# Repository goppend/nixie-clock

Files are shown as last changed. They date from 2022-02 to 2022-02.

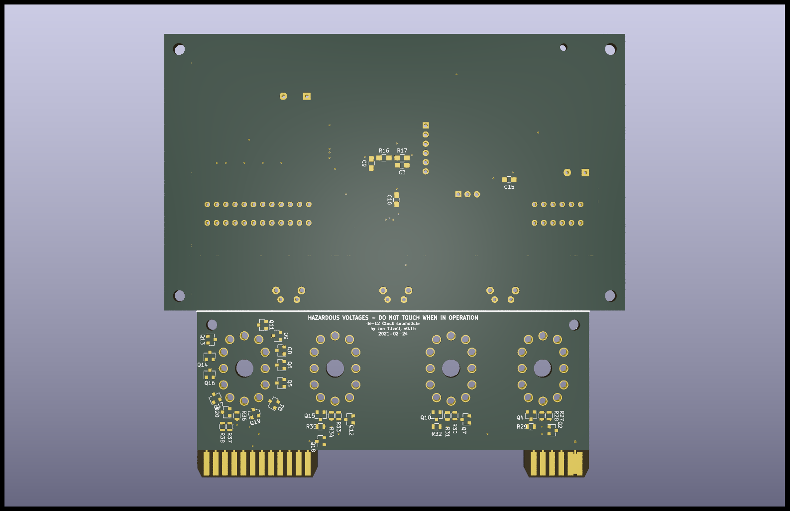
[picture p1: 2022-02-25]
pics/main reverse.png

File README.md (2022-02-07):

# Nixie Tube Clock (wip)

A nixie clock using IN-12 tubes, featuring a modular and efficient design.

## Todo
- [x] Port what I have to KiCad.
- [x] Fix existing problems.
- [x] Consider design changes, add last minute features, ERC.
- [x] Ensure layout is sound. DRC.
- [x] Have boards fabbed.
- [ ] (Awaiting boards/parts) Write firmware.
- [ ] Done!

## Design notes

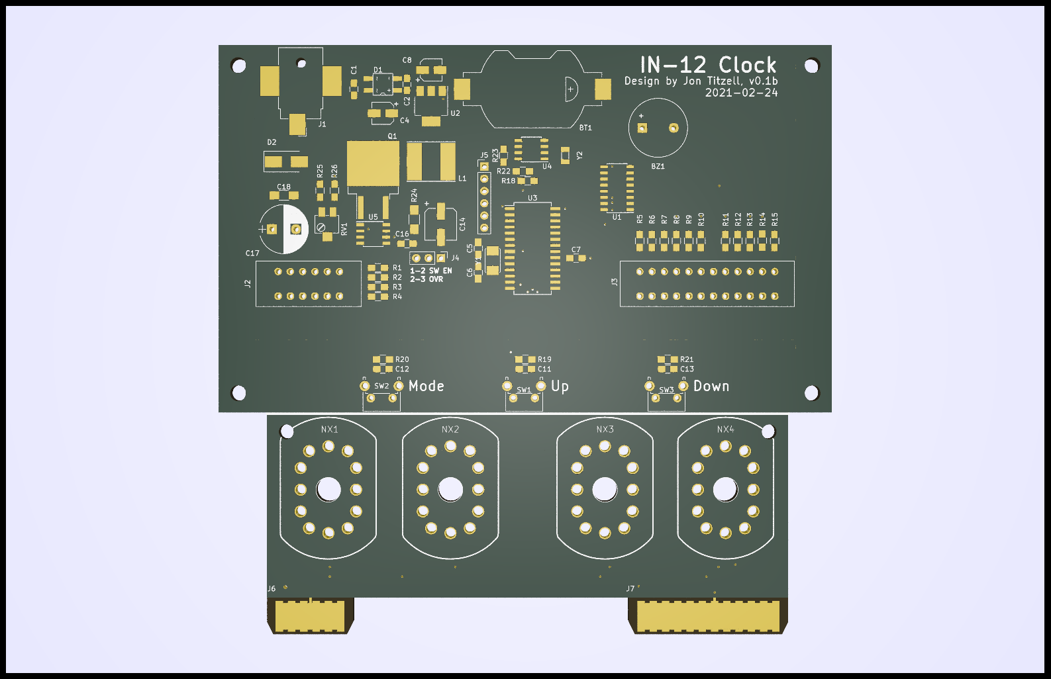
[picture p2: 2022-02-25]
pics/main.png

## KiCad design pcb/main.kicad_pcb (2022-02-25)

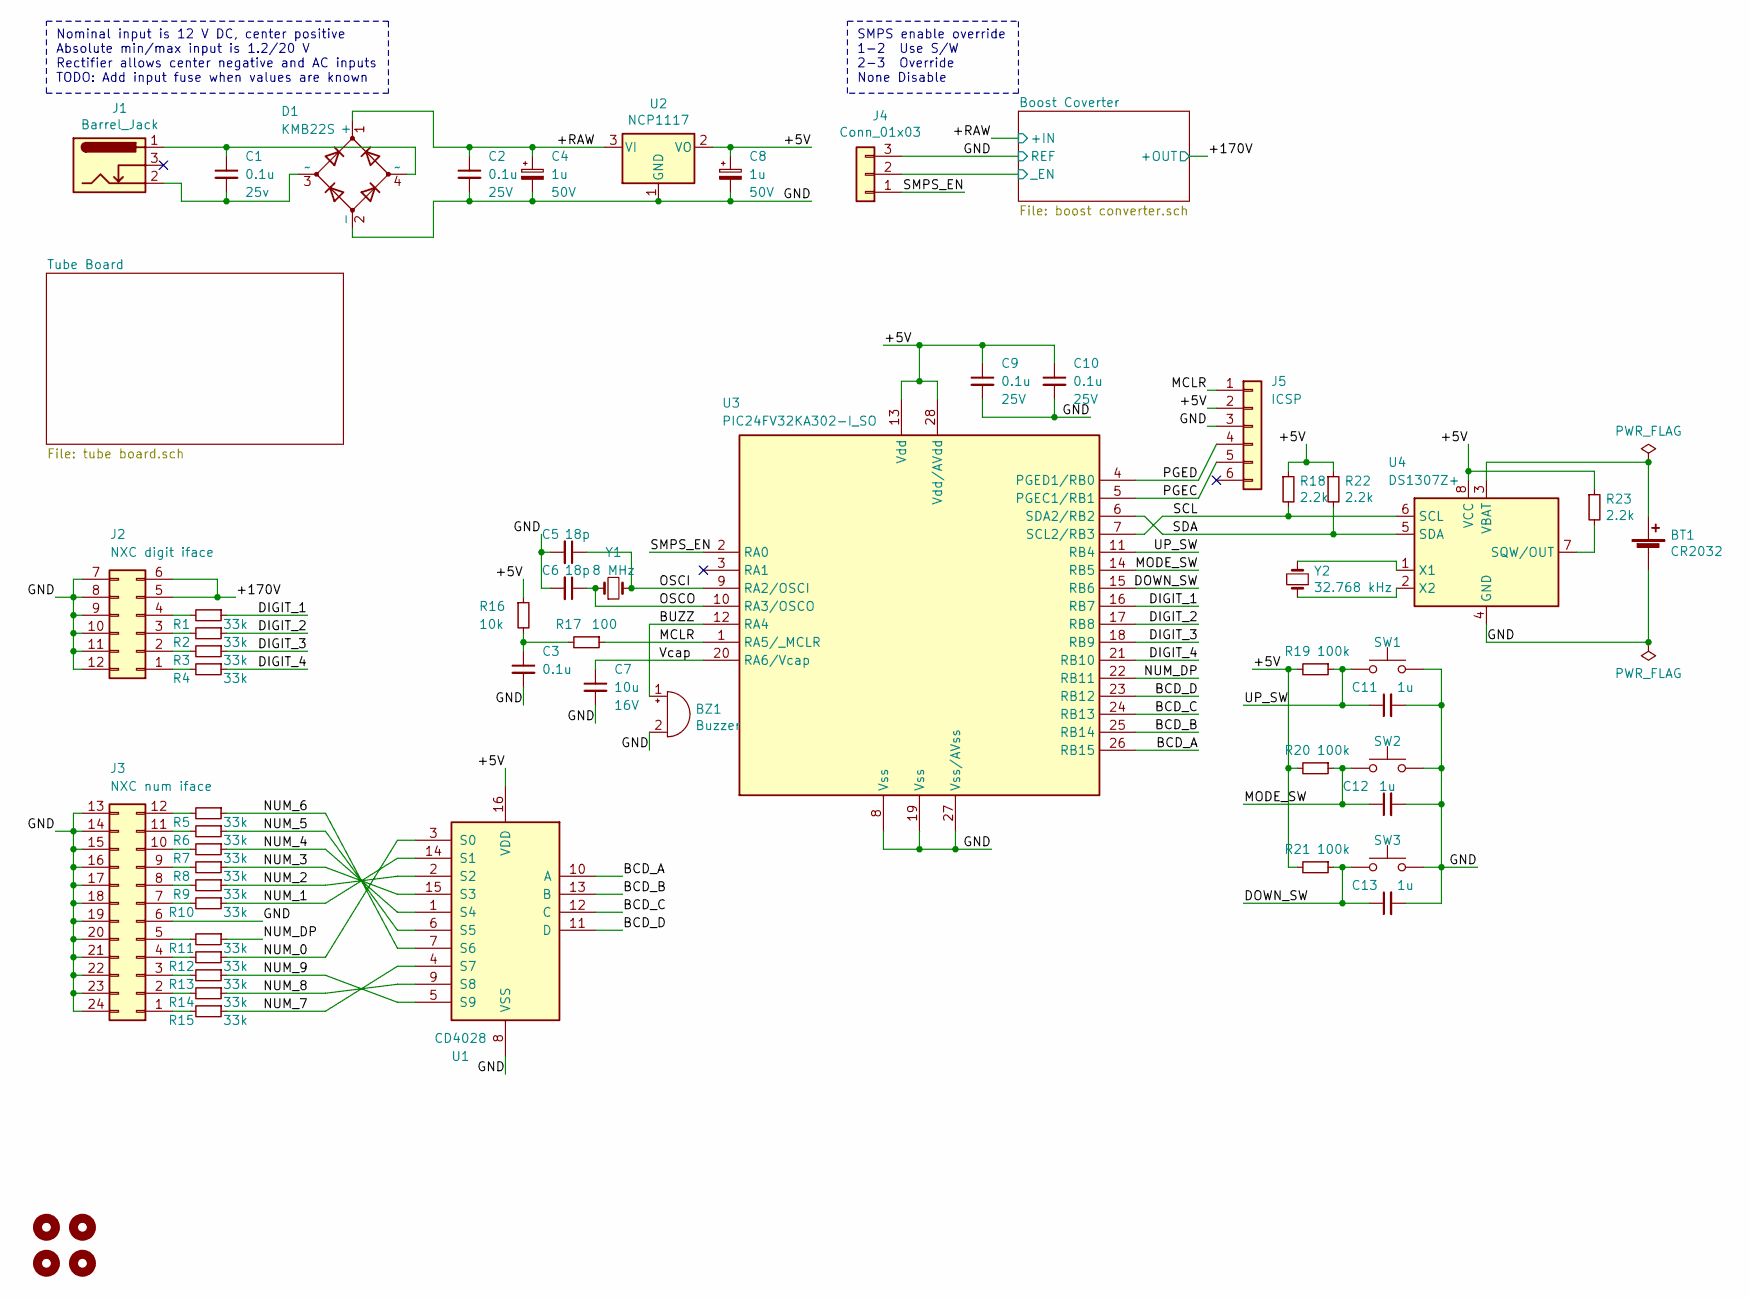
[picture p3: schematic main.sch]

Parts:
BT1: CR2032; BU2032SM-BT-GTR; Rating N/A
BZ1: Buzzer; Buzzer_12x9.5RM7.6; Rating 5V 50mA
C1: 0.1u; C_0805_HandSoldering; Rating 25v
C2, C3, C9, C10: 0.1u; C_0805_HandSoldering; Rating 25V
C4, C8: 1u; CP_Elec_4x5.3; Rating 50V
C5, C6: 18p; C_0805_HandSoldering; Rating 50V
C7: 10u; C_0805_HandSoldering; Rating 16V
C11, C12, C13: 1u; C_0805_HandSoldering; Rating 25V
D1: KMB22S; Diode-SMC_KMB22S-MBS; Rating 60V
H1, H2, H3, H4: MountingHole; MountingHole_3.2mm_M3; Rating N/A; Digikey Page N/A
J1: Barrel_Jack; Barrel_Jack_CUI_PJ-036AH-SMT; Rating N/A
J2: NXC digit iface; Sullins-EBC06DCWN; Rating N/A
J3: NXC num iface; Sullins-EBC12DCWN; Rating N/A
J4: Conn_01x03; Pin_Header_Straight_1x03_Pitch2.54mm; Rating N/A
J5: ICSP; Pin_Header_Straight_1x06_Pitch2.54mm; Rating N/A
R1, R2, R3, R4, R5, R6, R7, R8, R9, R10, R11, R12, R13, R14, R15: 33k; R_0805_HandSoldering; Rating 1/8W
R16: 10k; R_0805_HandSoldering; Rating 1/8W
R17: 100; R_0805_HandSoldering; Rating 1/8W
R18, R22, R23: 2.2k; R_0805_HandSoldering; Rating 1/8W
R19, R20, R21: 100k; R_0805_HandSoldering; Rating 1/8W
SW1, SW2, SW3: Tactile SPST; SW_Tactile_SPST_Angled_PTS645Vx58-2LFS; Rating N/A
U1: CD4028; SOIC-16_3.9x9.9mm_Pitch1.27mm; Rating 18V
U2: NCP1117; SOT-223-3_TabPin2; Rating 5V
U3: PIC24FV32KA302-I_SO; SOIC-28W_7.5x18.7mm_Pitch1.27mm; Rating 5V
U4: DS1307Z+; SOIC-8_3.9x4.9mm_Pitch1.27mm; Rating 5V
Y1: 8 MHz; Crystal-Abracom_ABM3-5.0x3.2; Rating ±20ppm
Y2: 32.768 kHz; Crystal-Vectron_VMK3-3.2x1.5; Rating ±20ppm

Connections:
/+5V: C8.1, C9.1, C10.1, J5.2, R16.1, R18.1, R19.2, R20.2, R21.2, R22.1, R23.1, U1.16 (VDD), U2.2 (VO), U3.13 (Vdd), U3.28 (Vdd/AVdd), U4.8 (VCC)
/+170V: J2.5, J2.6; also elsewhere on the board
/+RAW: C2.1, C4.1, D1.1 (+), U2.3 (VI); also elsewhere on the board
/BCD_A: U1.10 (A), U3.26 (RB15)
/BCD_B: U1.13 (B), U3.25 (RB14)
/BCD_C: U1.12 (C), U3.24 (RB13)
/BCD_D: U1.11 (D), U3.23 (RB12)
/BUZZ: BZ1.1 (-), U3.12 (RA4)
/Boost Coverter/_EN: J4.2; also elsewhere on the board
/DIGIT_1: R1.1, U3.16 (RB7)
/DIGIT_2: R2.1, U3.17 (RB8)
/DIGIT_3: R3.1, U3.18 (RB9)
/DIGIT_4: R4.1, U3.21 (RB10)
/DOWN_SW: C13.1, R21.1, SW3.1, U3.15 (RB6)
/GND: BT1.2 (-), BZ1.2 (+), C2.2, C3.2, C4.2, C5.2, C6.2, C7.2, C8.2, C9.2, C10.2, C11.2, C12.2, C13.2, D1.2 (-), J2.7, J2.8, J2.9, J2.10, J2.11, J2.12, J3.6, J3.13, J3.14, J3.15, J3.16, J3.17, J3.18, J3.19, J3.20, J3.21, J3.22, J3.23, J3.24, J4.3, J5.3, SW1.2, SW2.2, SW3.2, U1.8 (VSS), U2.1 (GND), U3.8 (Vss), U3.19 (Vss), U3.27 (Vss/AVss), U4.4 (GND); also elsewhere on the board
/MCLR: J5.1, R17.1, U3.1 (RA5/_MCLR)
/MODE_SW: C12.1, R20.1, SW2.1, U3.14 (RB5)
/NUM_0: R12.1, U1.3 (S0)
/NUM_1: R10.1, U1.14 (S1)
/NUM_2: R9.1, U1.2 (S2)
/NUM_3: R8.1, U1.15 (S3)
/NUM_4: R7.1, U1.1 (S4)
/NUM_5: R6.1, U1.6 (S5)
/NUM_6: R5.1, U1.7 (S6)
/NUM_7: R15.1, U1.4 (S7)
/NUM_8: R14.1, U1.9 (S8)
/NUM_9: R13.1, U1.5 (S9)
/NUM_DP: R11.1, U3.22 (RB11)
/OSCI: C5.1, U3.9 (RA2/OSCI), Y1.2
/OSCO: C6.1, U3.10 (RA3/OSCO), Y1.1
/PGEC: J5.5, U3.5 (PGEC1/RB1)
/PGED: J5.4, U3.4 (PGED1/RB0)
/SCL: R18.2, U3.7 (SCL2/RB3), U4.6 (SCL)
/SDA: R22.2, U3.6 (SDA2/RB2), U4.5 (SDA)
/SMPS_EN: J4.1, U3.2 (RA0)
/UP_SW: C11.1, R19.1, SW1.1, U3.11 (RB4)
/Vcap: C7.1, U3.20 (RA6/Vcap)
unnamed: BT1.1 (+), U4.3 (VBAT)
unnamed: C1.1, D1.4 (~~), J1.1
unnamed: C1.2, D1.3 (~~), J1.2
unnamed: C3.1, R16.2, R17.2
unnamed: J2.1, R4.2
unnamed: J2.2, R3.2
unnamed: J2.3, R2.2
unnamed: J2.4, R1.2
unnamed: J3.1, R15.2
unnamed: J3.2, R14.2
unnamed: J3.3, R13.2
unnamed: J3.4, R12.2
unnamed: J3.5, R11.2
unnamed: J3.7, R10.2
unnamed: J3.8, R9.2
unnamed: J3.9, R8.2
unnamed: J3.10, R7.2
unnamed: J3.11, R6.2
unnamed: J3.12, R5.2
unnamed: R23.2, U4.7 (SQW/OUT)
unnamed: U4.1 (X1), Y2.2
unnamed: U4.2 (X2), Y2.1

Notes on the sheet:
SMPS enable override 1-2 Use S/W 2-3 Override None Disable
Nominal input is 12 V DC, center positive Absolute min/max input is 1.2/20 V Rectifier allows center negative and AC inputs TODO: Add input fuse when values are known

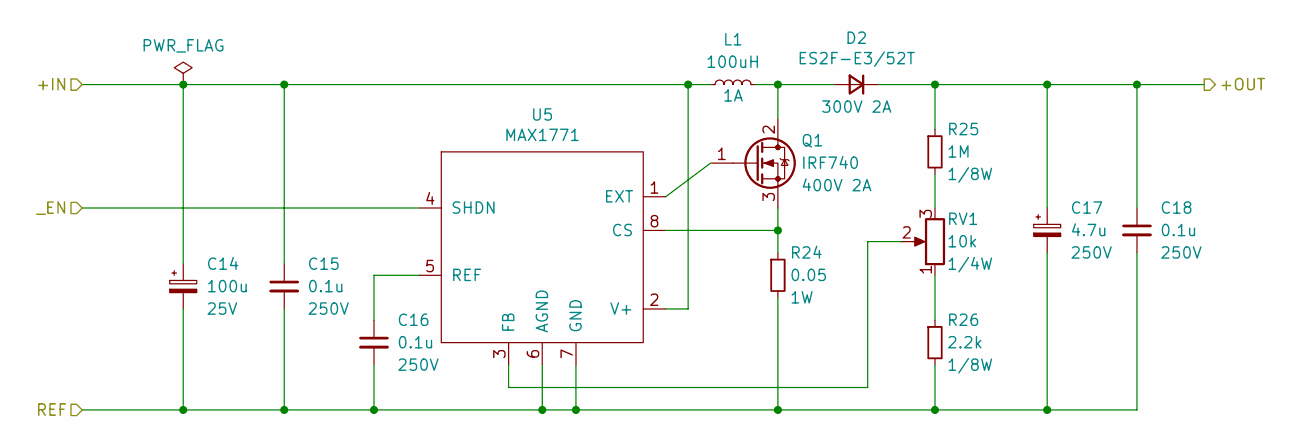
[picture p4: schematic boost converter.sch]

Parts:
C14: 100u; CP_Elec_6.3x5.8; Rating 25V
C15, C16: 0.1u; C_0805_HandSoldering; Rating 250V
C17: 4.7u; CP_Radial_D10.0mm_P5.00mm; Rating 250V
C18: 0.1u; C_1206_HandSoldering; Rating 250V
D2: ES2F-E3/52T; D_SMB_Handsoldering; Rating 300V 2A
L1: 100uH; Inductor_Taiyo-Yuden_NR-80xx_HandSoldering; Rating 1A
Q1: IRF740; TO-263-2; Rating 400V 2A
R24: 0.05; R_1206_HandSoldering; Rating 1W
R25: 1M; R_0805_HandSoldering; Rating 1/8W
R26: 2.2k; R_0805_HandSoldering; Rating 1/8W
RV1: 10k; Potentiometer_Trimmer_Bourns_3214X; Rating 1/4W
U5: MAX1771; SOIC-8_3.9x4.9mm_Pitch1.27mm; Rating 16.5V

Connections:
/+170V: C17.1, C18.1, D2.1 (K), R25.1; also elsewhere on the board
/+RAW: C14.1, C15.1, L1.1, U5.2 (V+); also elsewhere on the board
/Boost Coverter/_EN: U5.4 (SHDN); also elsewhere on the board
/GND: C14.2, C15.2, C16.2, C17.2, C18.2, R24.2, R26.2, U5.6 (AGND), U5.7 (GND); also elsewhere on the board
unnamed: C16.1, U5.5 (REF)
unnamed: D2.2 (A), L1.2, Q1.2 (D)
unnamed: Q1.1 (G), U5.1 (EXT)
unnamed: Q1.3 (S), R24.1, U5.8 (CS)
unnamed: R25.2, RV1.3
unnamed: R26.1, RV1.1
unnamed: RV1.2, U5.3 (FB)

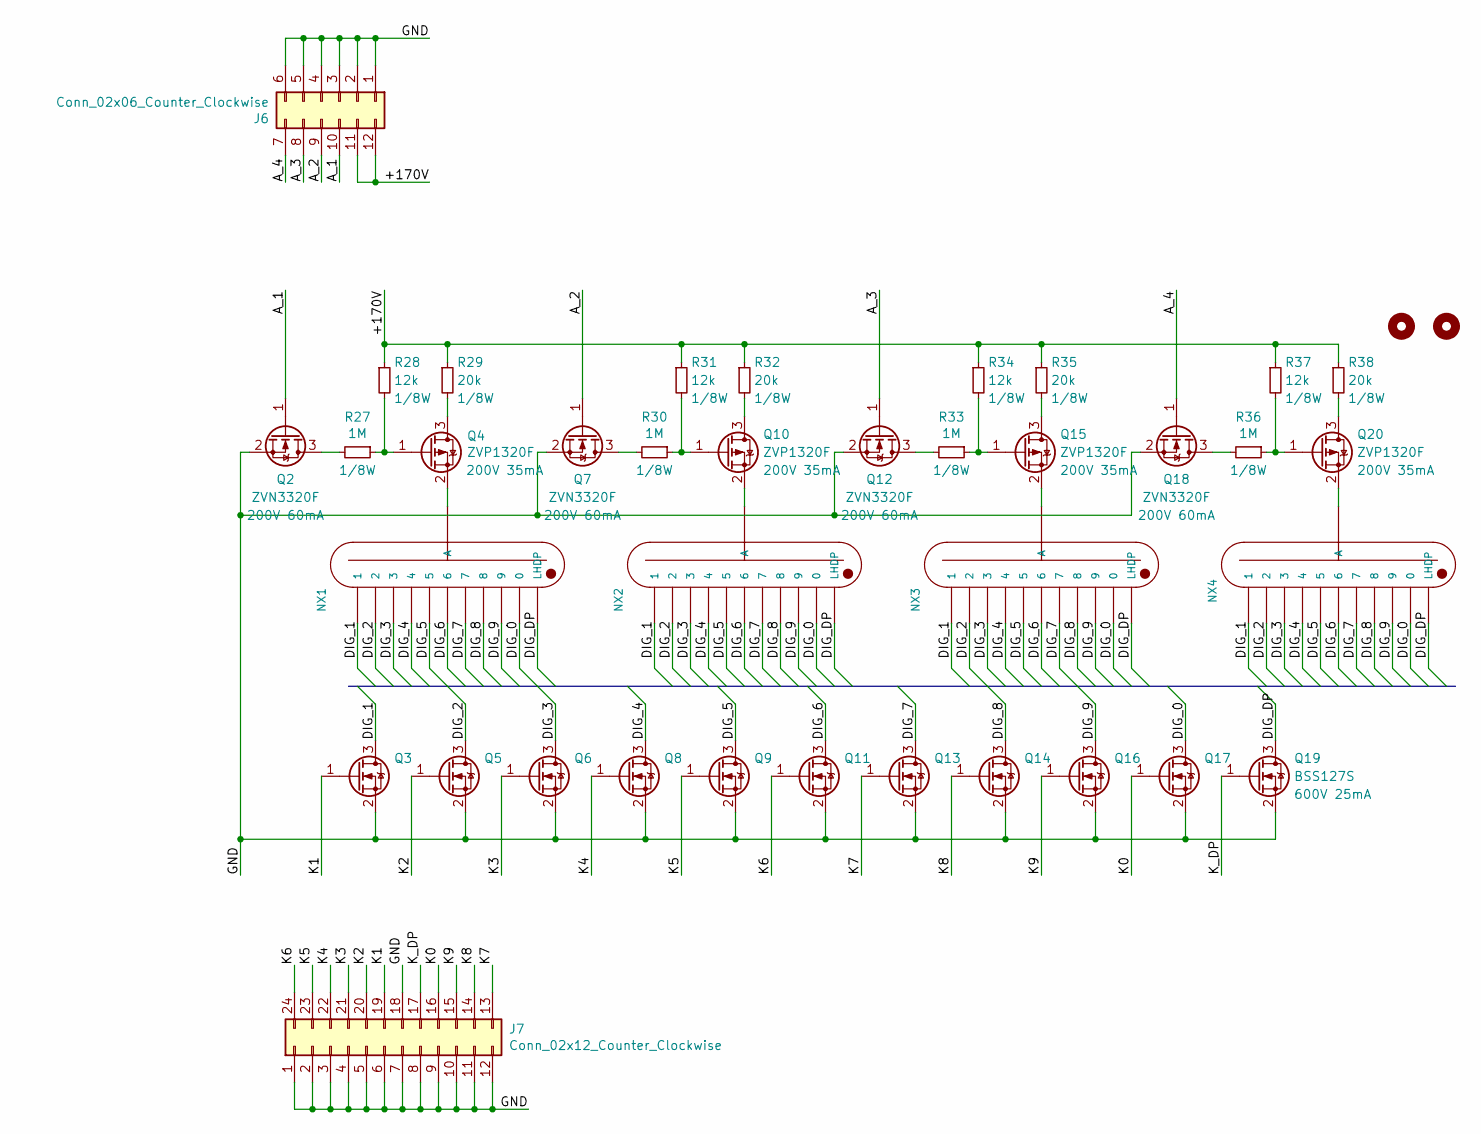
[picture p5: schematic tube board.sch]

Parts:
H5, H6: 3mm; MountingHole_3mm; Rating N/A; Digikey Page N/A
J6: Conn_02x06_Counter_Clockwise; Sullins-EBC06DCWN-Mating-Edge; Rating N/A; Digikey Page N/A
J7: Conn_02x12_Counter_Clockwise; Sullins-EBC12DCWN-Mating-Edge; Rating N/A; Digikey Page N/A
NX1, NX2, NX3, NX4: IN-12A; IN-12-Socket; Rating 170V; Digikey Page N/A
Q2, Q7, Q12, Q18: ZVN3320F; SOT-23; Rating 200V 60mA
Q3, Q5, Q6, Q8, Q9, Q11, Q13, Q14, Q16, Q17, Q19: BSS127S; SOT-23; Rating 600V 25mA
Q4, Q10, Q15, Q20: ZVP1320F; SOT-23; Rating 200V 35mA
R27, R30, R33, R36: 1M; R_0805; Rating 1/8W
R28, R31, R34, R37: 12k; R_0805; Rating 1/8W
R29, R32, R35, R38: 20k; R_0805; Rating 1/8W

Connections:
/Tube Board/+170V: J6.11, J6.12, R28.1, R29.1, R31.1, R32.1, R34.1, R35.1, R37.1, R38.1
/Tube Board/A_1: J6.10, Q2.1 (G)
/Tube Board/A_2: J6.9, Q7.1 (G)
/Tube Board/A_3: J6.8, Q12.1 (G)
/Tube Board/A_4: J6.7, Q18.1 (G)
/Tube Board/DIG_0: NX1.0, NX2.0, NX3.0, NX4.0, Q17.3 (D)
/Tube Board/DIG_1: NX1.1, NX2.1, NX3.1, NX4.1, Q3.3 (D)
/Tube Board/DIG_2: NX1.2, NX2.2, NX3.2, NX4.2, Q5.3 (D)
/Tube Board/DIG_3: NX1.3, NX2.3, NX3.3, NX4.3, Q6.3 (D)
/Tube Board/DIG_4: NX1.4, NX2.4, NX3.4, NX4.4, Q8.3 (D)
/Tube Board/DIG_5: NX1.5, NX2.5, NX3.5, NX4.5, Q9.3 (D)
/Tube Board/DIG_6: NX1.6, NX2.6, NX3.6, NX4.6, Q11.3 (D)
/Tube Board/DIG_7: NX1.7, NX2.7, NX3.7, NX4.7, Q13.3 (D)
/Tube Board/DIG_8: NX1.8, NX2.8, NX3.8, NX4.8, Q14.3 (D)
/Tube Board/DIG_9: NX1.9, NX2.9, NX3.9, NX4.9, Q16.3 (D)
/Tube Board/DIG_DP: NX1.LHDP, NX2.LHDP, NX3.LHDP, NX4.LHDP, Q19.3 (D)
/Tube Board/GND: J6.1, J6.2, J6.3, J6.4, J6.5, J6.6, J7.1, J7.2, J7.3, J7.4, J7.5, J7.6, J7.7, J7.8, J7.9, J7.10, J7.11, J7.12, J7.18, Q2.2 (S), Q3.2 (S), Q5.2 (S), Q6.2 (S), Q7.2 (S), Q8.2 (S), Q9.2 (S), Q11.2 (S), Q12.2 (S), Q13.2 (S), Q14.2 (S), Q16.2 (S), Q17.2 (S), Q18.2 (S), Q19.2 (S)
/Tube Board/K0: J7.16, Q17.1 (G)
/Tube Board/K1: J7.19, Q3.1 (G)
/Tube Board/K2: J7.20, Q5.1 (G)
/Tube Board/K3: J7.21, Q6.1 (G)
/Tube Board/K4: J7.22, Q8.1 (G)
/Tube Board/K5: J7.23, Q9.1 (G)
/Tube Board/K6: J7.24, Q11.1 (G)
/Tube Board/K7: J7.13, Q13.1 (G)
/Tube Board/K8: J7.14, Q14.1 (G)
/Tube Board/K9: J7.15, Q16.1 (G)
/Tube Board/K_DP: J7.17, Q19.1 (G)
unnamed: NX1.A, Q4.2 (S)
unnamed: NX2.A, Q10.2 (S)
unnamed: NX3.A, Q15.2 (S)
unnamed: NX4.A, Q20.2 (S)
unnamed: Q2.3 (D), R27.2
unnamed: Q4.1 (G), R27.1, R28.2
unnamed: Q4.3 (D), R29.2
unnamed: Q7.3 (D), R30.2
unnamed: Q10.1 (G), R30.1, R31.2
unnamed: Q10.3 (D), R32.2
unnamed: Q12.3 (D), R33.2
unnamed: Q15.1 (G), R33.1, R34.2
unnamed: Q15.3 (D), R35.2
unnamed: Q18.3 (D), R36.2
unnamed: Q20.1 (G), R36.1, R37.2
unnamed: Q20.3 (D), R38.2

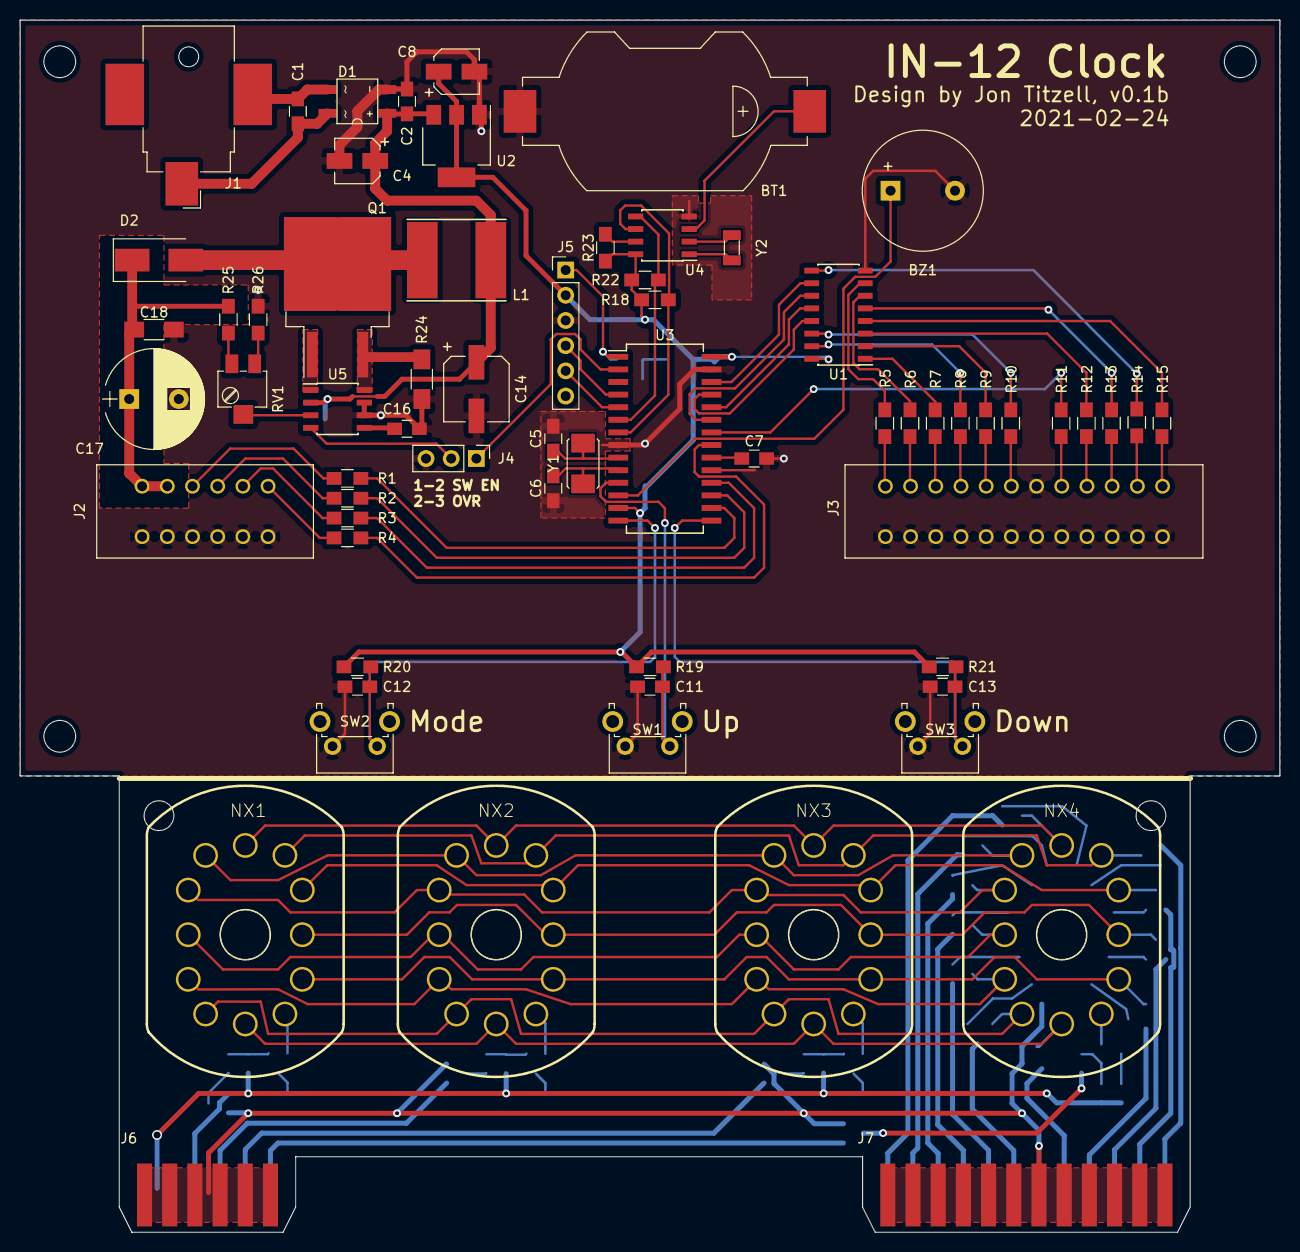
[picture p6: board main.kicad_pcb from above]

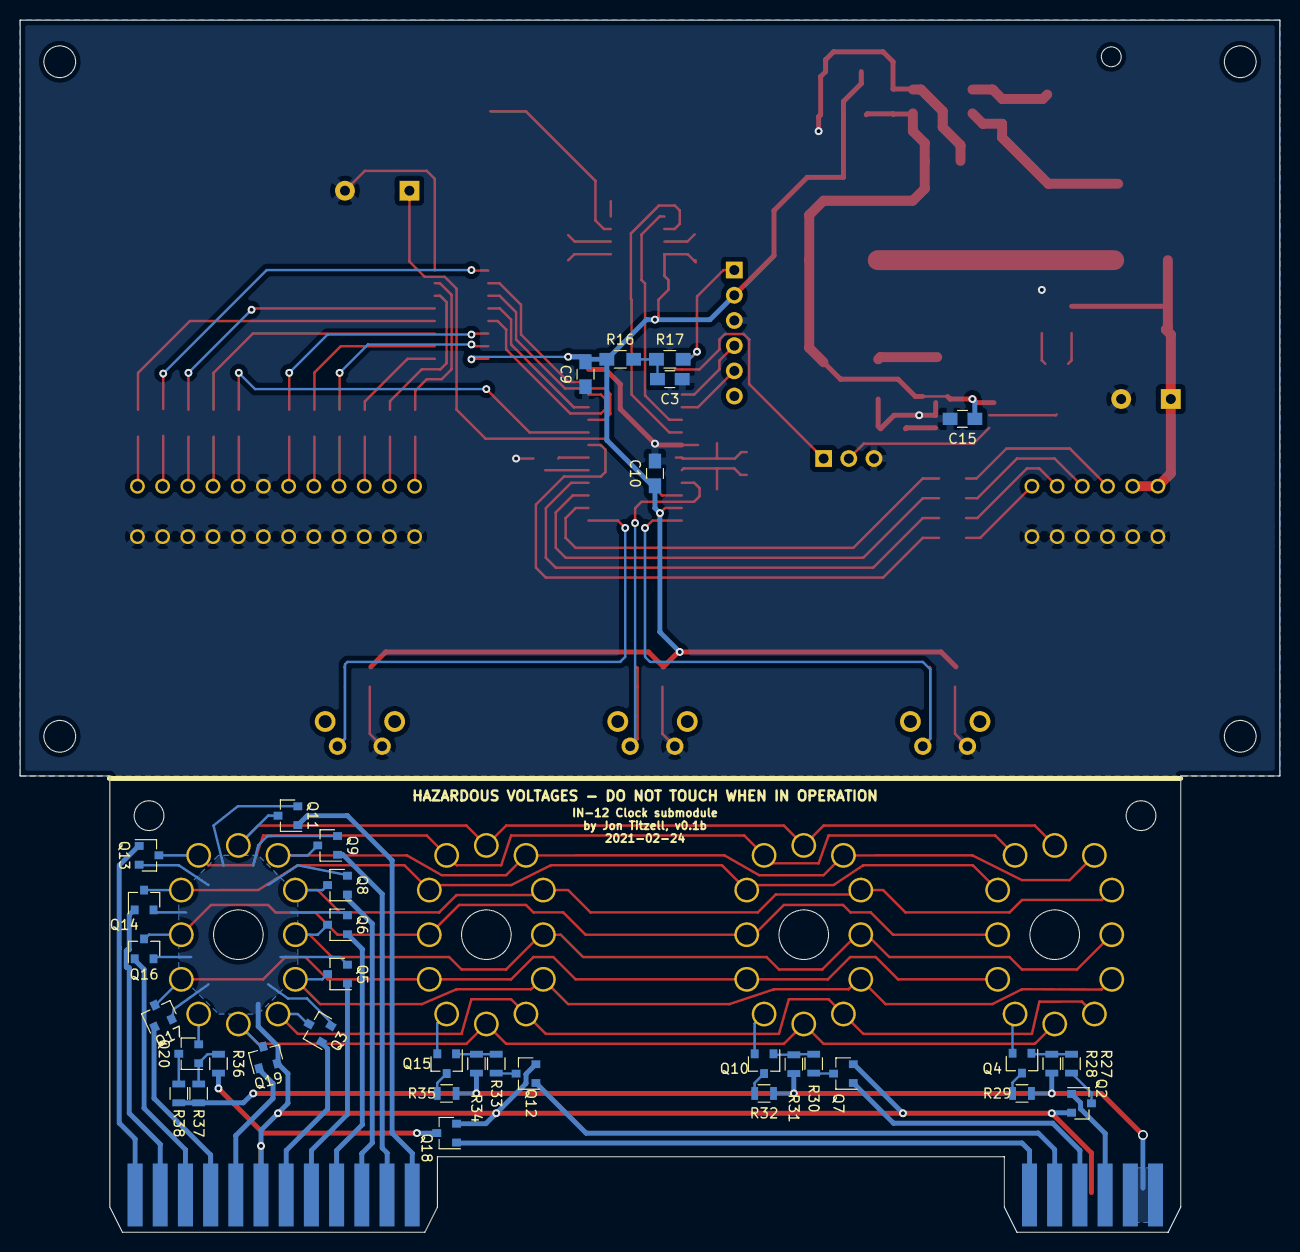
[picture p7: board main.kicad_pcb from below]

Board: 2 copper layers, 127.0 x 122.2 mm, 109 parts (37 on the bottom side), 110 nets.

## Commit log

2022-01-19 Add old project files to repo
    [base.sch, main.sch]
2022-01-30 Remove old DesignSpark project, recreate it with KiCad.
    [base.sch, boost converter.sch, main.kicad_pcb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]
2022-02-02 Update PCB and schematic files with mostly small tweaks. Added DRC rules added to .pro, and changes on layout and footprints to reflect that.
    [boost converter.sch, main.kicad_pcb, main.sch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]
2022-02-04 Add alternate parts for BOM, adjust micro to be more compatible with new PIC24FJ series parts.
    [boost converter.sch, main.kicad_pcb, main.sch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]
2022-02-07 Update schematic with some better part selection, reducing BOM. Update PCB for panelized fabrication.
    [boost converter.sch, main.kicad_pcb, main.sch]
2022-02-24 Fix some problems with pcb, crystals and rectifier using wrong footprints. Octal decoder had Vss and Vdd swapped.
    [main.kicad_pcb, main.sch, tube board.sch]
2022-02-24 Update board to reflect new crystal and rectifier footprint. Update silkscreen ver/date, add new board renders and schematic plots.
    [main.kicad_pcb]
